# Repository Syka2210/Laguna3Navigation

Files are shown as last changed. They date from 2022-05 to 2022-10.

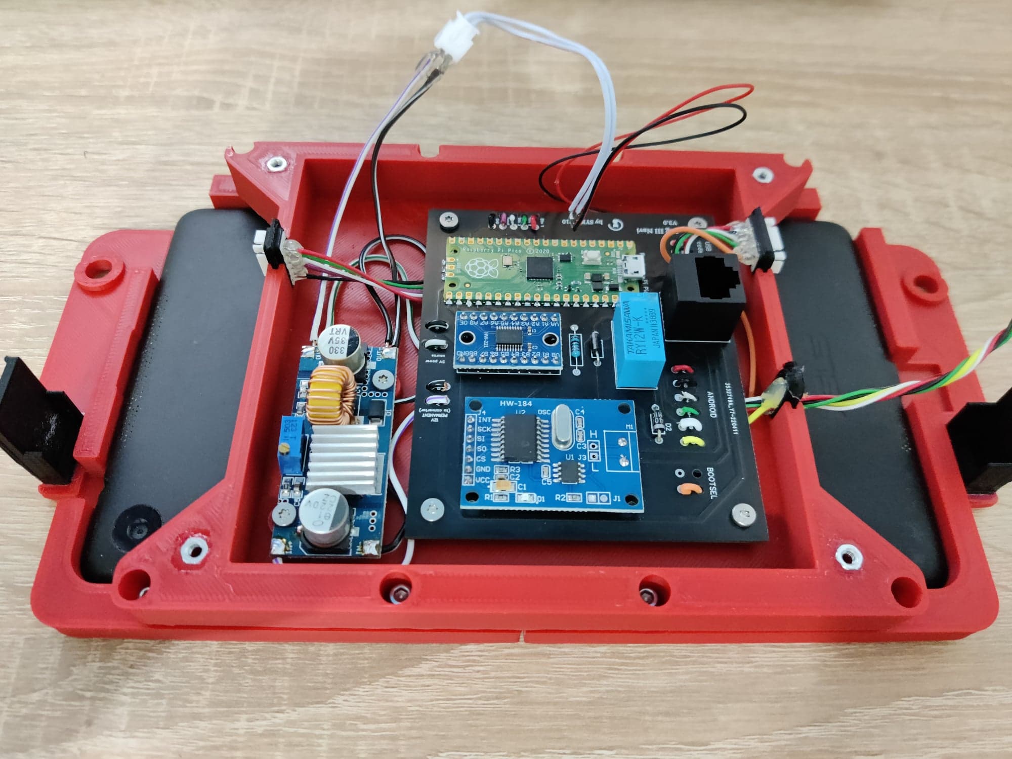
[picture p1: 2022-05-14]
Datasheets/Images/Git_image_1.jpg

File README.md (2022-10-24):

# Laguna3Navigation
   A custom navigation module for Renault Laguna III, replacing the OE screen with an Android device that comunicates with the multimedia CAN BUS network. 
Back view             |  Front view
:-------------------------:|:-------------------------:
 |  

   This project started as an alternative to the limited navigation unit that the Laguna III is equipped with (those until the R-link variant). The only difference from the aftermarket versions is the use of the OE radio. I've decided to keep the radio unit and find a way to display the info received from it to the Android device implemented, along with other useful info such as: weather info, ETA to the destination.
Also, the use of the Android navigation (Google Maps, Waze), and other apps (Spotify, YouTube, etc) was one of the main reasons for the implementation of this new multimedia interface.

   This new unit was planned as a plug in module. So no cutting of car wiring, screen fixture plastics or other trims of the car, only adding a few additional wires for a microphone and permanent power supply. 
Beeing a plug in module, the steering wheel satellite commands and the console joystick were mandatory. The satellite commands comunicate only with the radio, so that was no issue. On the other hand, the joystick for the navigation module was linked to that through CAN BUS, and that allowed me to remap the controls to my needs easily. More on that later. 

   For the android device, I had different options, with ups and downs:
- an Android tablet (Nexus 7). I have choosed that mainly for the fact that there is a kernel that allows the tablet to run in a deep sleep mode with very low curent consumption, and open in 2 seconds (no boot, since there is no complete shut down). I haven't found other tablets that have this kind of kernel, so this model was the only option. The cons - the tablet is old, runs slow, overheats quickly, hard to come by. 
- a Raspberry pi running LineageOS. This came with a few disadvantages. Big booting time, need to aquire additional modules (GPS, display, Bluetooth in some cases), high cost. On the other hand, it is more accessible (well not lately, the reason being the shortage of semiconductors), easier to work with, easier to upgrade with newer pi models, GPIO pins. 

   I've decided to use the nexus 7, at least for the first project. 

   After that being settled, the next issue at hand was acquiring the message packages sent from the radio to the navigation module ( well a part of it which is the display, so will refer to it on the rest of the presentation as the "display"). This multimedia unit uses a bitrate of 500 kbps, so accessing it was the easy part. "Decoding" all the frames received... now that was a little tricky. With the help of other who have tried something similar, but opposed to what I was trying to accomplish, I have managed to identify the following:
- each unit sends a message to announce that it is present and ready to work to the other units that may need the data from it. At the same time, this initial unit is expecting another messages from the other units to check for acknowledgement. Like pinging a server... Sort of. 
- the text messages with the icons and alignment are send using the ISO-TO (ISO 15765-2) standard. After each frame, the display sends acknowledgement frames to the radio, so I had to address that issue, or the radio would stop sending the next frames.

For reading the CAN Buss network, I started from an Arduino Uno with a MCP2515 module, and worked my way up to a Raspberry Pi Pico (due to the higher capabilities of processing data, higher Ram and flash memory, castellated holes for slim mounting, and let's be onest, for the slick look of it). 
This data needed to be sent to the Android device, and processed to show an elegant interface, similar to the original one, in order to navigate through the menu easily. That meant an app was required. So with the help of Google (literally), I've developed an app that receives the data from the Pico through the wired serial connection, and display our messages and icons same as the OE display. The app can be found here https://github.com/Syka2210/Laguna3HUD
OE display menu             |  New module display menu
:-------------------------:|:-------------------------:
 | 

This app also creates a log file with all the data received for debugging purposes. It can be enabled or disabled, depending on how the unit is performing.

The message sent to the android device from Pico consist of a string with identifiers at the beginning and at the end, and with a separator for spliting the string easily. The Pico .ino file have a detailed info for explaining how each of the function works.
Message identifier  |  Data to be displayed |  end of message identifier
:-------------------------:|:-------------------------:|:-----------------:
view_43 | FM : 3 (highlighted box) : 92.90 : 100.00 : 120.20 : KISS FM : PRO FM : DIGI FM : 1 : 2 : 3 | end_string

For the development of this project, the following sources were used:
- reverse engineering the Renault multimedia unit: https://hackaday.io/project/27439-smart-car-radio/log/67874-reverse-engineering-the-renault-update-list-display-part-1
- Android library for comunicating with Arduino through USB: https://github.com/OmarAflak/Arduino-Library
- Removing the battery from Nexus and powering it from external soucrces for eliminating the risc of battery swelling during heat summer days and risking a fire hazard: https://www.reddit.com/r/timurskernel/comments/3lui2n/video_how_to_remove_n7_battery_and_wire_direct_to/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
- Timur's kernel for deep sleep mode: https://www.reddit.com/r/timurskernel/comments/51lhgf/v40_for_android_601/   https://github.com/mehrvarz/msm-marshmallow-tm-usbhost-charge

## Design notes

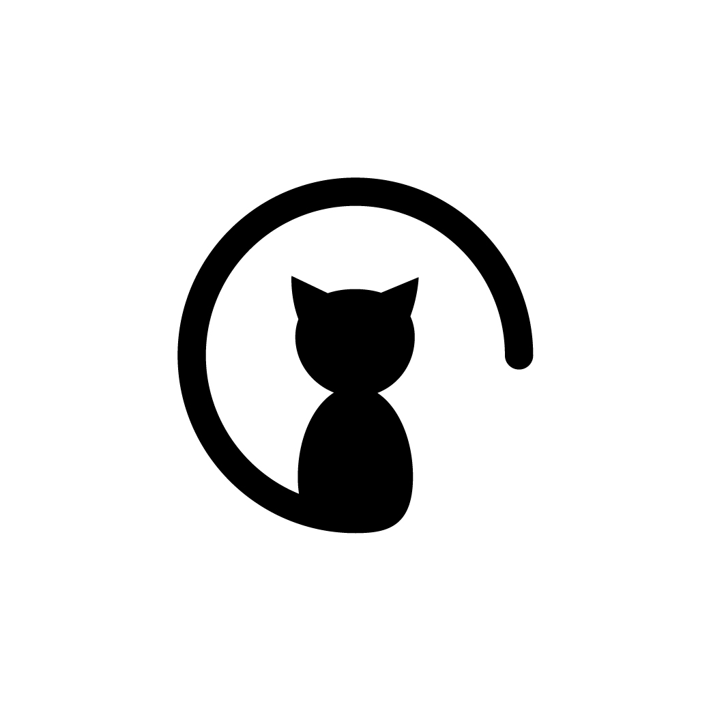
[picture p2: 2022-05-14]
PCB/Cat (29)/Cat-29.jpg

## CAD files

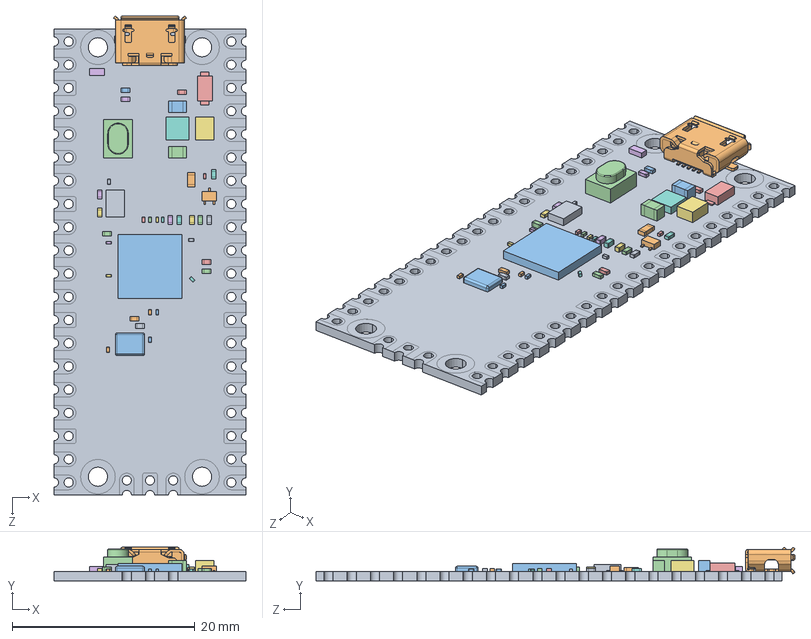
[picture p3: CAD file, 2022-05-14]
3D parts/Parts/Raspberry Pi Pico-R3.SLDASM
21.0 x 3.69 x 52.4 mm
PCB, Raspberry Pi Pico-R3.STEP
MicroUSB Port, Raspberry Pi Pico-R3.STEP
RP2040 Microcontroller, Raspberry Pi Pico-R3.STEP
SW1, Tact Switch, Raspberry Pi Pico-R3.STEP
D1, Diode, Schottky, Raspberry Pi Pico-R3.STEP
D2, QSME-C194, LED, Raspberry Pi Pico-R3.STEP
L1, Inductor, Raspberry Pi Pico-R3.STEP
U2, RT6150B-33GQW, Buck Boost Converter, Raspberry Pi Pico-R3.STEP
U3, W25Q16JVUXIQ, Serial NOR Flash 16 Mbit, Raspberry Pi Pico-R3.STEP
Q1, MOSFET, DMG1012T, Raspberry Pi Pico-R3.STEP
X1, X12M000000S096, 12 Mhz Crystal Resonator, Raspberry Pi Pico-R3.STEP
SMD Resistor, Configurable, Raspberry Pi Pico-R3_R1.STEP
SMD Resistor, Configurable, Raspberry Pi Pico-R3_R2.STEP
SMD Resistor, Configurable, Raspberry Pi Pico-R3_R3.STEP
SMD Resistor, Configurable, Raspberry Pi Pico-R3_R4.STEP
SMD Resistor, Configurable, Raspberry Pi Pico-R3_R5.STEP
SMD Resistor, Configurable, Raspberry Pi Pico-R3_R6.STEP
SMD Resistor, Configurable, Raspberry Pi Pico-R3_R7.STEP
SMD Resistor, Configurable, Raspberry Pi Pico-R3_R8.STEP
SMD Resistor, Configurable, Raspberry Pi Pico-R3_R9.STEP
SMD Resistor, Configurable, Raspberry Pi Pico-R3_R10.STEP
SMD Resistor, Configurable, Raspberry Pi Pico-R3_R11.STEP
SMD Resistor, Configurable, Raspberry Pi Pico-R3_R12.STEP
SMD Resistor, Configurable, Raspberry Pi Pico-R3_R13.STEP
SMD Resistor, Configurable, Raspberry Pi Pico-R3_R14.STEP
SMD Resistor, Configurable, Raspberry Pi Pico-R3_R15.STEP
SMD Capacitor, Configurable, Raspberry Pi Pico-R3_C1.STEP
SMD Capacitor, Configurable, Raspberry Pi Pico-R3_C2.STEP
SMD Capacitor, Configurable, Raspberry Pi Pico-R3_C3.STEP
SMD Capacitor, Configurable, Raspberry Pi Pico-R3_C4.STEP
SMD Capacitor, Configurable, Raspberry Pi Pico-R3_C5.STEP
SMD Capacitor, Configurable, Raspberry Pi Pico-R3_C6.STEP
SMD Capacitor, Configurable, Raspberry Pi Pico-R3_C7.STEP
SMD Capacitor, Configurable, Raspberry Pi Pico-R3_C8.STEP
SMD Capacitor, Configurable, Raspberry Pi Pico-R3_C9.STEP
SMD Capacitor, Configurable, Raspberry Pi Pico-R3_C10.STEP
SMD Capacitor, Configurable, Raspberry Pi Pico-R3_C11.STEP
SMD Capacitor, Configurable, Raspberry Pi Pico-R3_C12.STEP
SMD Capacitor, Configurable, Raspberry Pi Pico-R3_C13.STEP
SMD Capacitor, Configurable, Raspberry Pi Pico-R3_C14.STEP
SMD Capacitor, Configurable, Raspberry Pi Pico-R3_C15.STEP
SMD Capacitor, Configurable, Raspberry Pi Pico-R3_C16.STEP
SMD Capacitor, Configurable, Raspberry Pi Pico-R3_C17.STEP
SMD Capacitor, Configurable, Raspberry Pi Pico-R3_C18.STEP

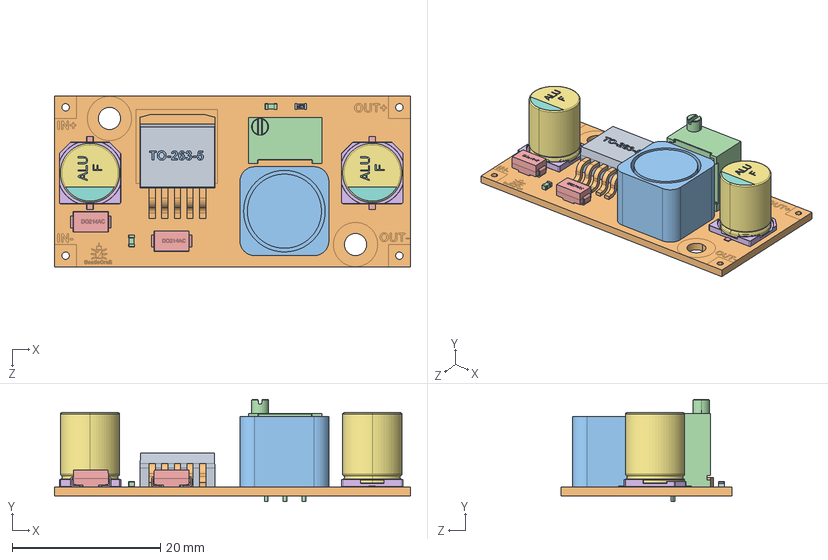
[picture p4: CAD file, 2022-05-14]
3D parts/Carcasa Navigatie V4.0/LM2596_DC-DC_CONVERTER.SLDASM
48.0 x 13.8 x 23.0 mm
User Library-DC-DC MODULE LM2596s_User Library-TO-263-5_TO-263-5_Body_1.STEP
User Library-DC-DC MODULE LM2596s_User Library-TO-263-5_TO-263-5_Leads_1.STEP
User Library-DC-DC MODULE LM2596s_User Library-TO-263-5_TO-263-5_Marking_1.STEP
User Library-DC-DC MODULE LM2596s_C0603.STEP x 2
User Library-DC-DC MODULE LM2596s_User Library-ALU-F_Pins_1.STEP x 2
User Library-DC-DC MODULE LM2596s_User Library-ALU-F_Fuss_1.STEP x 2
User Library-DC-DC MODULE LM2596s_User Library-ALU-F_K_X_F6rper_1.STEP x 2
User Library-DC-DC MODULE LM2596s_User Library-ALU-F_Beschriftung_1.STEP x 2
User Library-DC-DC MODULE LM2596s_R0603.STEP
BASE_LM2596.STEP
INDUCTOR_LM2596.STEP
POT_LM2596.STEP
DIODE_LM2596.STEP x 2

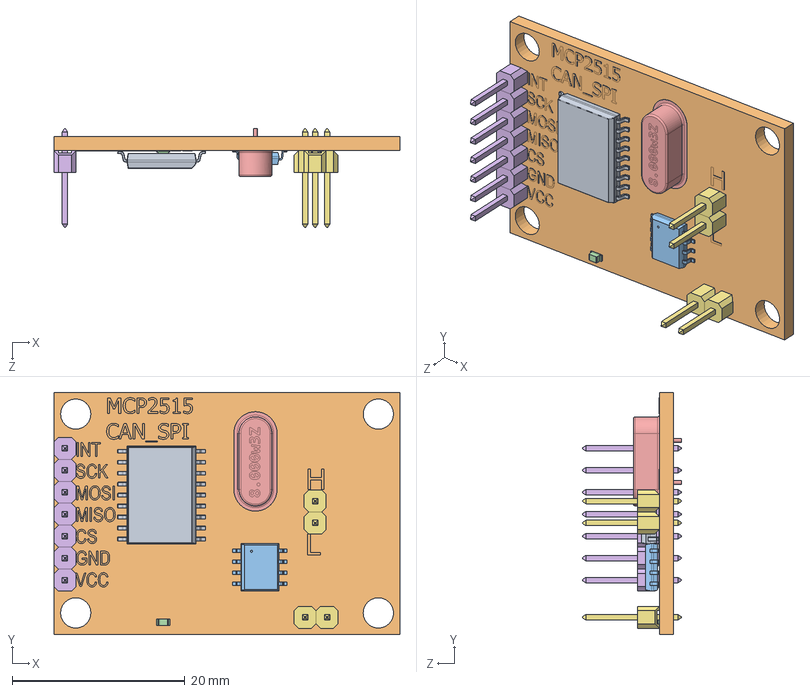
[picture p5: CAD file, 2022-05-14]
3D parts/Carcasa Navigatie V4.0/MCP2515 CAN_SPI.SLDASM
40.0 x 28.0 x 11.5 mm
so_ic_wide_18pin.stp
PCB CAN SPI.stp
so_ic_8pin.stp
led_green_0603.stp
ABRACON_ABL-8.000MHZ-B2.stp
Pin Header 7 x 1 TH 2.54mm Pitch.stp
Pin Header 2 x1 TH 2.54mm Pitch.stp x 2

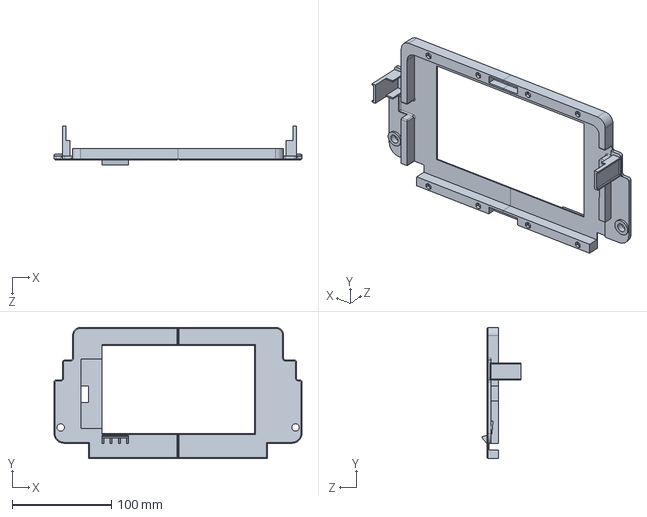
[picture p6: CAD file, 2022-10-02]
3D parts/Carcasa Navigatie V4.0/display case v4.0.SLDPRT
250.2 x 132.5 x 39.0 mm

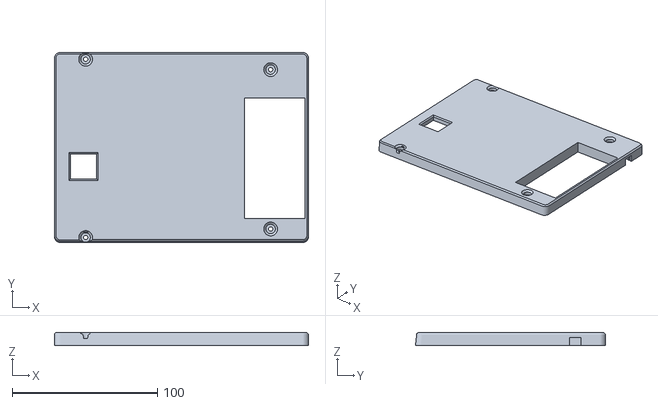
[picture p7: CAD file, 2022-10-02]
3D parts/Carcasa Navigatie V4.0/STL/PCB case - upper v4.0.STL
174.9 x 130.9 x 9.00

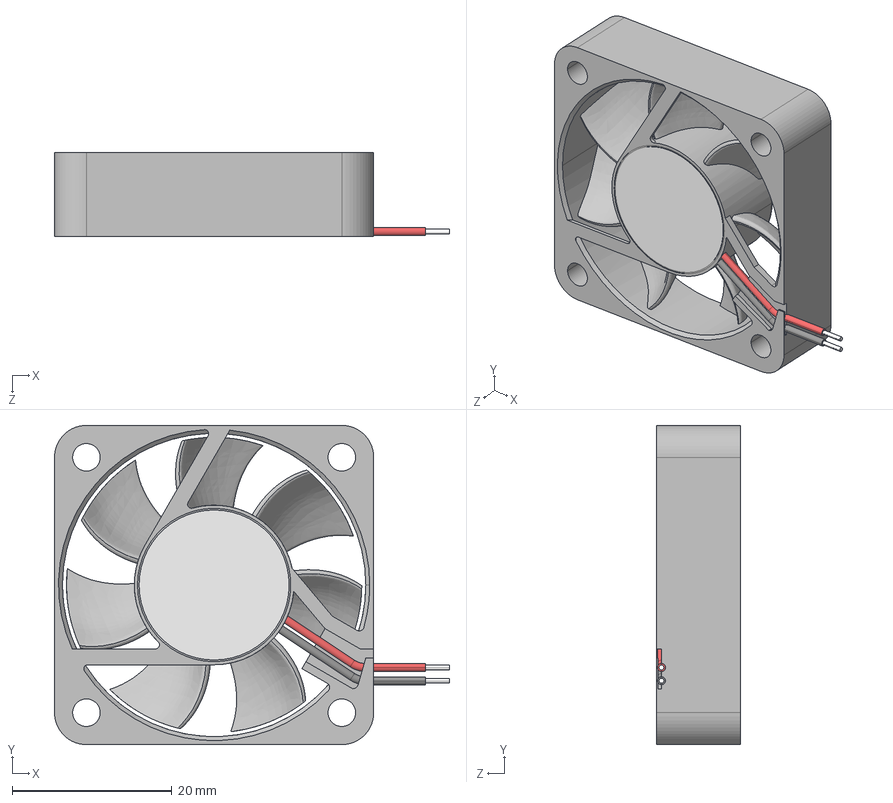
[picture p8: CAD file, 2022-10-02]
3D parts/Parts/40x40x10 DC Fan.STEP
49.5 x 40.0 x 10.5 mm

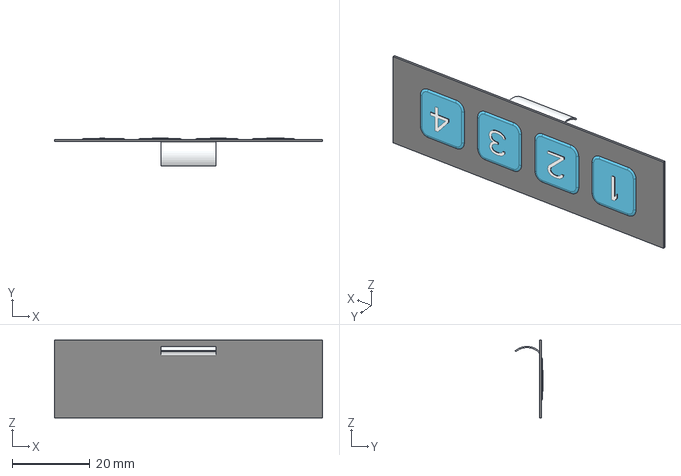
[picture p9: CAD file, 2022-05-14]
3D parts/STEP/membrane_1x4-keypad.stp
69.0 x 7.10 x 20.0 mm

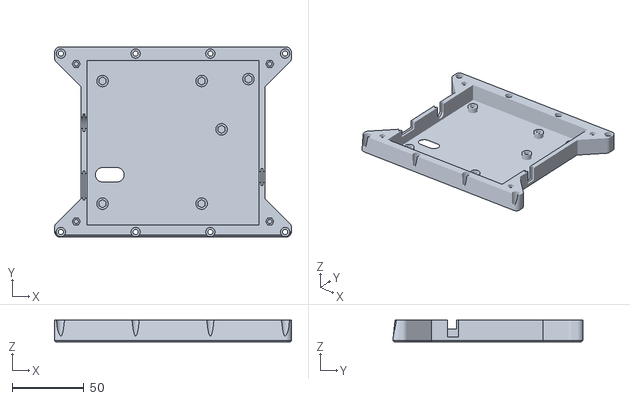
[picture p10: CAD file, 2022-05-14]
3D parts/STL files/PCB case v3.0 - lower.STL
164.9 x 132.4 x 15.0

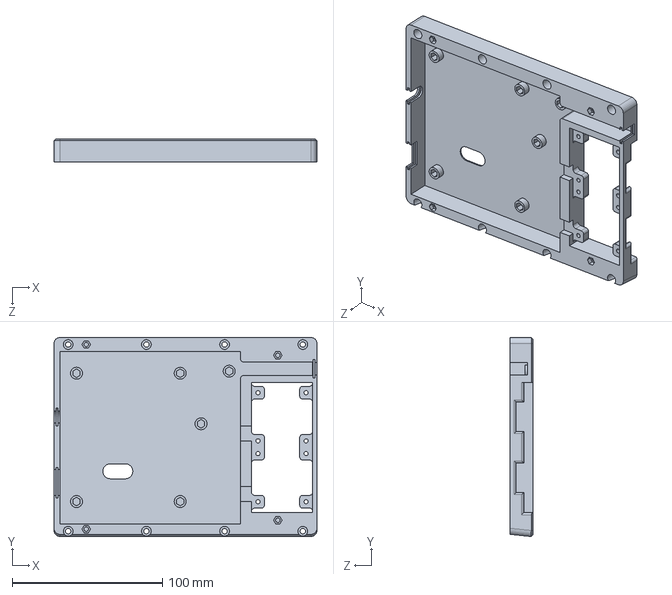
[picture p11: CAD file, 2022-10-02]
3D parts/Carcasa Navigatie V4.0/PCB case v4.0.sldprt
174.9 x 132.4 x 15.0 mm

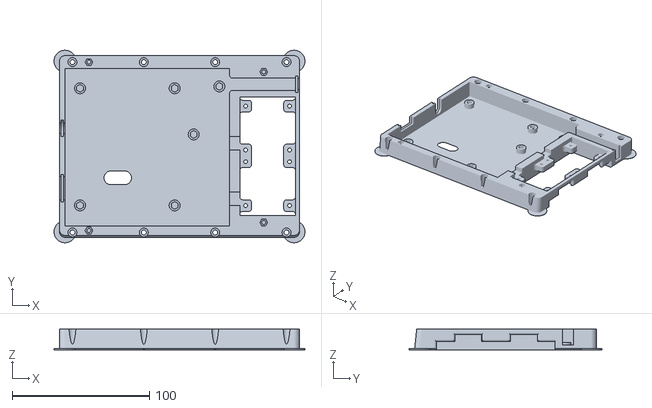
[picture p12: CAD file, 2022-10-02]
3D parts/Carcasa Navigatie V4.0/STL/PCB case - lower v4.0.STL
182.9 x 140.4 x 15.0

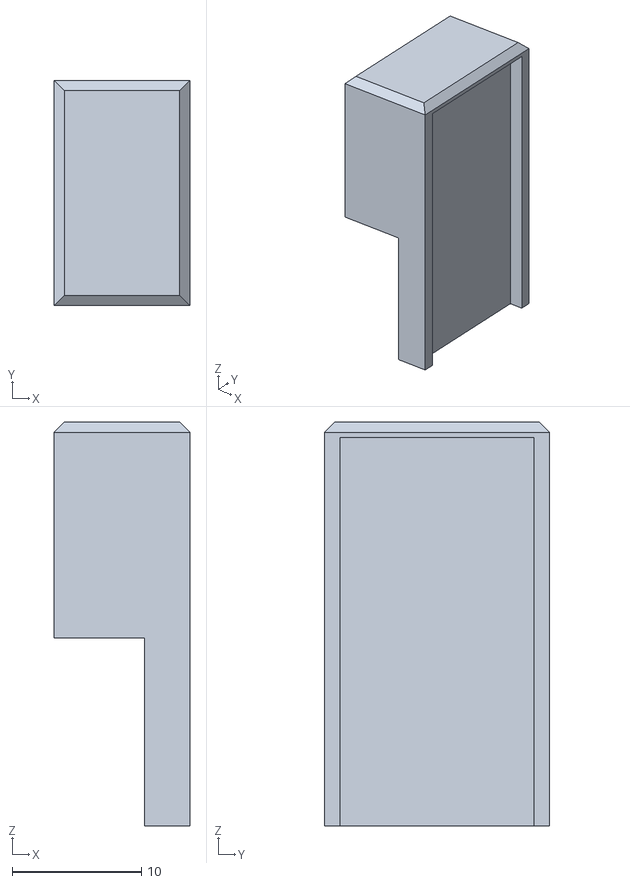
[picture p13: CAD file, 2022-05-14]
3D parts/STL files/Right clips v3.STL
10.5 x 17.4 x 31.2

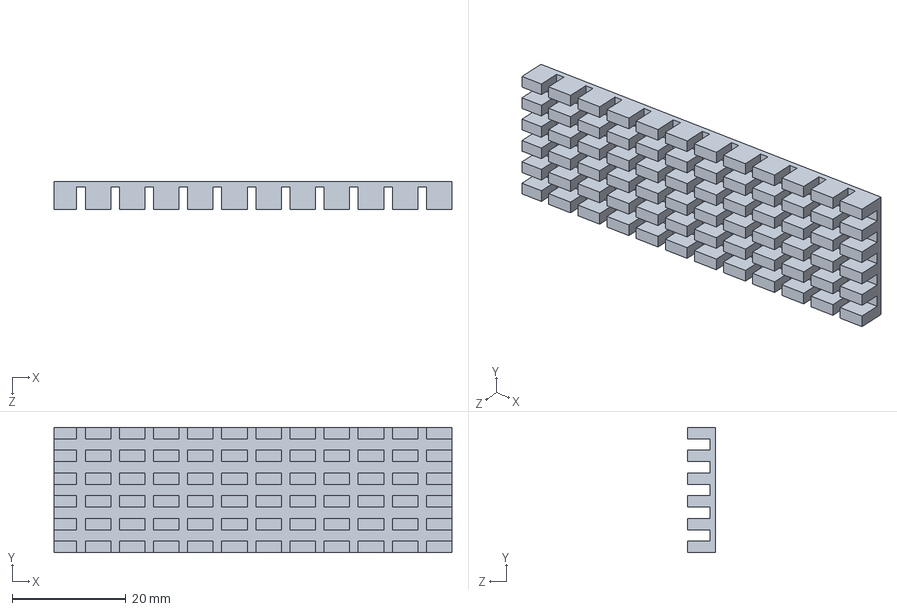
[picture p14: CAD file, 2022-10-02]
3D parts/Carcasa Navigatie V4.0/Radiator CPU.SLDPRT
70.0 x 22.0 x 5.00 mm

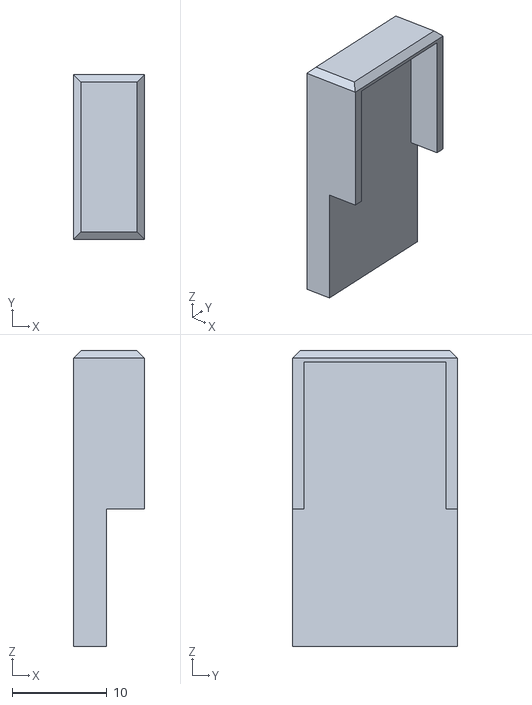
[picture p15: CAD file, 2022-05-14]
3D parts/STL files/Left clips v3.STL
7.50 x 17.4 x 31.2

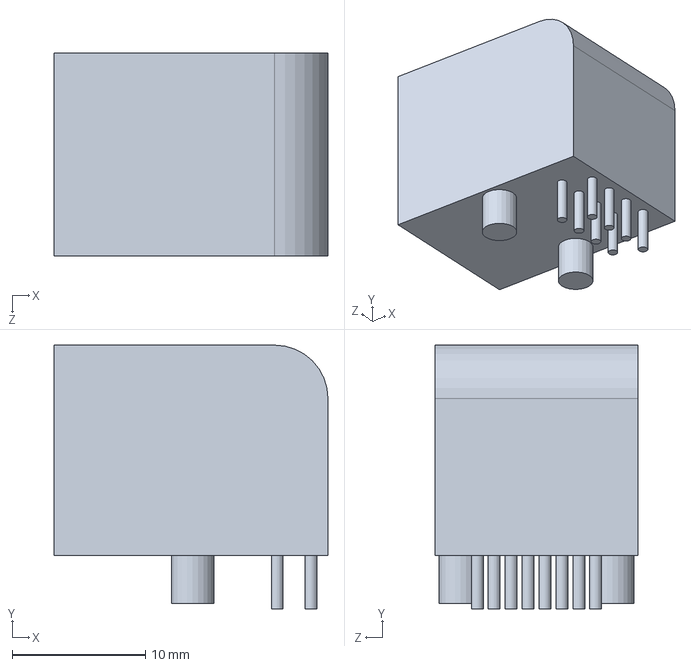
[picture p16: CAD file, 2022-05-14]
3D parts/Parts/rj45 90degree.SLDPRT
20.6 x 19.8 x 15.2 mm

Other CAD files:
3D parts/Parts/Fan_30x30x8_5V_2pin.stp
3D parts/Carcasa Navigatie V4.0/membrane_1x4-keypad.SLDPRT
3D parts/STL files/Latch V3.STL
3D parts/Parts/XH2.54 3p.SLDPRT
3D parts/Carcasa Navigatie V2.0/ACT112.SLDPRT
3D parts/Carcasa Navigatie V2.0/Display case PCB box v2.0.SLDPRT
3D parts/Carcasa Navigatie V2.0/Latch V1.2.SLDPRT
3D parts/Carcasa Navigatie V2.0/display case v1.3.SLDPRT
3D parts/Carcasa Navigatie V3.0/PCB case v3.0.sldprt
3D parts/Carcasa Navigatie V3.0/Radiator CPU.SLDPRT
3D parts/Carcasa Navigatie V3.0/display case v3.0.SLDPRT
3D parts/Carcasa Navigatie V4.0/Back_cover(display case).STL
3D parts/Carcasa Navigatie V4.0/Back_cover(display case).sldprt
3D parts/Carcasa Navigatie V4.0/Cable ring connector - 4 pins.SLDPRT
3D parts/Carcasa Navigatie V4.0/Cable ring connector.SLDPRT
3D parts/Carcasa Navigatie V4.0/Cable ring.SLDPRT
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

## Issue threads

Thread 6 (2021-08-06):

Add rigidity to the front frame clips extrusions

Syka2210, 2021-08-06:
- [x] Add rigidity to the front frame clips extrusions, by making an assembly, on wich the extrusions to be printed along the height, for improved rigidity.

- [x] Add support for the AC mask in front of the frame

Syka2210, 2022-10-02:
Solved with the new version of the frame.

Closed 2022-10-02.

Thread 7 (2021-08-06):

LOG file

Syka2210, 2021-08-06:
Implement a log file in the android device, with data (visual aided, like bolded text etc.) receiveed from the arduino and the steps that the android app makes.
**_POSSIBLE ISSUE: when exiting app, the log might not save the data_**

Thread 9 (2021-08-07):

Update the pcb with ICSP code upload, shorter connection for the arduino usb, add a 5v stab transistor for the wake up signal, remove the diode( or use a zener one), change the connector (?),

Syka2210, 2021-08-07:

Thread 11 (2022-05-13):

Tablet overheats in hot days

Syka2210, 2022-05-13:
As an alternative, consider changing the Nexus 7 with an SBC (Odroid?), but that will limit the capabilities (no Sim card no GPS)

Syka2210, 2022-10-02:
A external radiator was added with two 40mm fans to force cool the processor.

Closed 2022-10-02.

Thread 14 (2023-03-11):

Nav joy light-on

garzazum, 2023-03-11:
Incredible job! possible you have figured out CAN sequence that enables nav joy lights-on / off ?
br

Syka2210, 2023-03-11:
I haven't mapped out all the frames, only the ones that interest me. But next time I sniff the can, I will look for it.

garzazum, 2023-03-11:
Thank you for reply, I was just curious if you have it stored somewhere in past. On my own I'm limiting to China Android + radio pilot + nav joy steering on promicro. Br

Syka2210, 2023-03-11:
I haven't mapped out all the frames, only the ones that interest me. But next time I sniff the can, I will look for it.
Edit. What android device are you using?

garzazum, 2023-03-12:
Regular budget China 32/2, 7' screen fits to original 7'' navi LIII screen/frame, because of Bose and external AMP had to use 4 channel Hi to LO converter.

Syka2210, 2023-03-12:
Could you send a link of it? I'm curious what are the possibilities of it.

garzazum, 2023-03-21:
It;s something like this... https://pl.aliexpress.com/item/1005003908694349.html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

garzazum, 2023-03-21:
Also found adapter allowing to connect wire tape from radio front panel so without cutting will grab also signals from front radio panel. https://pl.aliexpress.com/item/1005004411693590.html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

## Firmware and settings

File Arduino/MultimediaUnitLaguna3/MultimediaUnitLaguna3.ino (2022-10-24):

#include <ACAN2515.h>
#include <SPI.h>
#include <Keyboard.h>

//——————————————————————————————————————————————————————————————————————————————
// The Pico has two SPI peripherals, SPI and SPI1. Either (or both) can be used.
// The are no default pin assignments to these must be set explicitly.
//——————————————————————————————————————————————————————————————————————————————
static const byte MCP2515_SCK  = 18 ; // SCK input of MCP2515
static const byte MCP2515_MOSI = 19 ; // SDI input of MCP2515
static const byte MCP2515_MISO = 16 ; // SDO output of MCP2517

static const byte MCP2515_CS  = 17 ;  // CS input of MCP2515 (adapt to your design)
static const byte MCP2515_INT = 12 ;  // INT output of MCP2515 (adapt to your design)
//——————————————————————————————————————————————————————————————————————————————
//  MCP2515 Driver object
//——————————————————————————————————————————————————————————————————————————————
ACAN2515 can (MCP2515_CS, SPI, MCP2515_INT) ;
CANMessage canMsg;
//——————————————————————————————————————————————————————————————————————————————
//  MCP2515 Quartz: adapt to your design
//——————————————————————————————————————————————————————————————————————————————
static const uint32_t QUARTZ_FREQUENCY = 8UL * 1000UL * 1000UL ; // 8 MHz
//——————————————————————————————————————————————————————————————————————————————
//  Pins for the 4x1 keypad that will be used for controlling the navigation bar of the 
//  Android device, due to the fact that it will not be accesible (frame)
//——————————————————————————————————————————————————————————————————————————————
const int backButton = 7;      // 4x1 keyboard -- button assigned for back 
const int homeButton = 8;      // 4x1 keyboard -- button assigned for home
const int appSwitchButton = 9; // 4x1 keyboard -- button assigned for app switch button
//——————————————————————————————————————————————————————————————————————————————
//  Disable or enable the log Function and the second UART data line (for debuging)
//  on pins GP0 and GP1.
//——————————————————————————————————————————————————————————————————————————————
bool logFileActive = true;
bool secondSerialActive = true;

unsigned long delayTime = 250;

unsigned char dataPackage[200];
char dataPackegePos;
int dataPackageLength;

char high_box;
String freq_box;
String last_menu;

String endString = "end_string";

String receivedMessage;
//--- Save the last main messages received in order to resend them if the app request it
String lastSource;
String lastMessage;
String lastVolume;

void sendToSerial(String viewType="zz", String frequencyType="zz", char highBox='z', String box_1x1="zz", String box_1x2="zz", String box_1x3="zz", String box_2x1="zz", String box_2x2="zz", String box_2x3="zz", String box_3x1="zz", String box_3x2="zz", String box_3x3="zz", char bass_sign='_', char bass_val='_', char treble_sign='_', char treble_val='_');

void setup() {
  //--- Start serial at highes baud rate for Android comunication
  Serial.begin(250000);
  Serial1.begin(250000);
  //--- There are no default SPI pins so they must be explicitly assigned
  SPI.setSCK(MCP2515_SCK);
  SPI.setTX(MCP2515_MOSI);
  SPI.setRX(MCP2515_MISO);
  SPI.setCS(MCP2515_CS);
  //--- Begin SPI
  SPI.begin () ;  
  //--- Configure ACAN2515
  Serial.println ("Configure ACAN2515") ;
  Serial1.println ("Configure ACAN2515") ;
  ACAN2515Settings settings (QUARTZ_FREQUENCY, 500UL * 1000UL) ; // CAN bit rate 500 kb/s - autovehicle frequency
  settings.mReceiveBufferSize = 100; // Buffer size set to 100 from 32
  settings.mRequestedMode = ACAN2515Settings::NormalMode ; // Select normal mode
  const uint16_t errorCode = can.begin (settings, [] { can.isr () ; }) ;
  //--- Turn the board LED on to check for functionality
  pinMode(LED_BUILTIN, OUTPUT);
  digitalWrite(LED_BUILTIN, HIGH);

  pinMode(backButton, INPUT_PULLUP);
  pinMode(homeButton, INPUT_PULLUP);
  pinMode(appSwitchButton, INPUT_PULLUP);
}

void logFunction(){
  //if (canMsg.id == 289){
      Serial.print("LOG-FILE:FRAME ID=");
      //Serial1.print("LOG-FILE:FRAME ID="); 
      Serial.print(canMsg.id);
      //Serial1.print(canMsg.id);
      for (int i=0; i<=7; i++){
        Serial.print(":");
        //Serial1.print(":");
        if (canMsg.data[i] < 16){
          Serial.print('0');
          //Serial1.print('0');
        } 
        Serial.print(canMsg.data[i], HEX);
        //Serial1.print(canMsg.data[i], HEX);
      }
      Serial.print(":");
      //Serial1.print(":);
      Serial.println(endString);
      //Serial1.println(endString);
  //}
}

void sendToSerial(String viewType, String frequencyType, char highBox, String box_1x1, String box_1x2, String box_1x3, String box_2x1, String box_2x2, String box_2x3, String box_3x1, String box_3x2, String box_3x3, char bass_sign, char bass_val, char treble_sign, char treble_val){
  String messagePack = "";
  if (viewType == "Error"){
    messagePack = viewType + ":" + frequencyType + ":" + endString;
    Serial.println(messagePack);
    //Serial1.println(messagePack);
  }else if (viewType == "requestMessage"){
    if (lastSource.length() > 0){
      Serial.println(lastSource);
      //Serial1.println(lastSource);
    }else{
      Serial.println("Error:last source string is empty!:end_string");
      Serial1.println("Error:last source string is empty!:end_string");
    }
    if (lastVolume.length() > 0){
      Serial.println(lastVolume);
      //Serial1.println(lastVolume);  
    }else{
      Serial.println("Error:last volume string is empty!:end_string");
      //Serial.println("Error:last volume string is empty!:end_string");
    }
    if (lastMessage.length() > 0){
      Serial.println(lastMessage);
      //Serial1.println(lastMessage);
    }else{
      Serial.println("Error:last message string is empty!:end_string");
      //Serial.println("Error:last message string is empty!:end_string");
    }
  }else if (viewType == "HighlightedBox"){
    messagePack = viewType + ":" + String(highBox) + ":" + endString;
    Serial.println(messagePack);
    //Serial1.println(messagePack);
  }else if (viewType == "view_c1"){
    messagePack = viewType + ":" + box_1x1 + ":" + box_1x2 + ":" + endString;
    lastMessage = messagePack;
    Serial.println(messagePack);
    //Serial1.println(messagePack);
  }else if (viewType == "freq_type"){
    messagePack = viewType + ":" + frequencyType + ":" + endString;
    Serial.println(messagePack);
    //Serial1.println(messagePack);
  }else if (viewType == "view_c3"){
    messagePack = viewType + ":" + box_1x1 + ":" + box_1x2 + ":" + box_1x3 + ":" + box_2x1 + ":" + box_2x2 + ":" + box_2x3 + ":" + endString;
    lastMessage = messagePack;
    Serial.println(messagePack);
    //Serial1.println(messagePack);
  }else if (viewType == "source"){
    messagePack = viewType + ":" + frequencyType + ":" + endString;
    Serial.println(messagePack);
    //Serial1.println(messagePack);
  }else if (viewType == "view_41"){
    messagePack = viewType + ":" + frequencyType + ":" + String(highBox) + ":" + box_1x1 + ":" + box_1x2 + ":" + box_1x3 + ":" + endString;
    lastMessage = messagePack;
    Serial.println(messagePack);
    //Serial1.println(messagePack);
  }else if (viewType == "device_volume"){
    messagePack = viewType + ":" + box_1x1 + ":" + endString;
    Serial.println(messagePack);
    //Serial1.println(messagePack);
  }else if (viewType == "view_43"){
    messagePack = viewType + ":" + frequencyType + ":" + String(highBox) + ":" + box_1x1 + ":" + box_1x2 + ":" + box_1x3 + ":" + box_2x1 + ":" + box_2x2 + ":" + box_2x3 + ":" + box_3x1 + ":" + box_3x2 + ":" + box_3x3 + ":" + endString;
    lastMessage = messagePack;
    Serial.println(messagePack);
    //Serial1.println(messagePack);
  }else if (viewType == "view_52"){
    messagePack = viewType + ":" + frequencyType + ":" + endString;
    lastMessage = messagePack;
    Serial.println(messagePack);
    //Serial1.println(messagePack);
  }else if (viewType == "view_63"){
    messagePack = viewType + ":" + box_1x1 + ":" + box_1x2 + ":" + box_1x3 + ":" + box_2x1 + ":" + box_2x2 + ":" + box_2x3 + ":" + endString;
    lastMessage = messagePack;
    Serial.println(messagePack);
    //Serial1.println(messagePack);
  }else if (viewType == "view_70"){
    messagePack = viewType + ":" + frequencyType + ":" + String(highBox) + ":" + endString;
    Serial.println(messagePack);
    //Serial1.println(messagePack);
  }else if (viewType == "view_73"){
    messagePack = viewType + ":" + String(highBox) + ":" + box_1x1 + ":" + box_1x2 + ":" + box_1x3 + ":" + box_2x1 + ":" + box_2x2 + ":" + box_2x3 + ":" + bass_sign + ":" + bass_val + ":" + treble_sign + ":" + treble_val + ":" + ":" + endString;
    lastMessage = messagePack;
    Serial.println(messagePack);
    //Serial1.println(messagePack);
  }
  else{
    Serial.print("viewType ");
    //Serial1.print("viewType ");
    Serial.print(viewType);
    //Serial1.print(viewType);
    Serial.println(" not found in sendToSerial method");
    //Serial1.println(" not found in sendToSerial method");
  }
}

bool bytesToArray(int arrayLength){
  int arrayPos = 0;
  bool loop = true;
  logFunction();
  for (int i = 2; i <= 7; i++){
    dataPackage[arrayPos] = canMsg.data[i];
    arrayPos++;
  }
  while (loop == true){
    if (can.receive (canMsg)){
      if (canMsg.id == 289){
        if (canMsg.data[0] == 0x10){
          Serial.println("Info:FAILED:Received new data package before ariving to the end of the previous one");
          break;
        }
        logFunction();
        for (int i = 1; i <= 7; i++){    
          dataPackage[arrayPos] = canMsg.data[i];
          if (arrayPos == arrayLength){
            loop = false;
            break;
          }else{
            arrayPos++;        
          }
        }
      }
    }
  }
  
  for (int i = 0; i <= arrayPos; i++){
    Serial.print(dataPackage[i], HEX);
    Serial.print(":");
  }
  Serial.println();

  if (arrayPos != arrayLength){
    Serial.print("Info:Error: data package length not identical to array => ");
    Serial.print(arrayPos);
    Serial.println(endString);
  }else{
    Serial.println("Info:Package length correct!!!");
  }

  Serial.println("------------------------------------------------------------");

  if (dataPackage[1] == 0x00 && dataPackage[0] == 0x20){
    highlighted_box(dataPackage[11]);
    return true;
  }
    
  if (dataPackage[1] == 0xC1 && dataPackage[5] != 0x00){
    Serial.println("entering view_C1");
    view_C1(arrayLength);
    return true;
  }
  if (dataPackage[1] == 0xC1 && dataPackage[5] == 0x00){
    freq_type(arrayLength);
    return true;
  }
  if (dataPackage[1] == 0xC3){
    Serial.println("entering view_C3");
    view_C3(arrayLength);
    return true;
  }
  
  if (dataPackage[1] == 0x41 && dataPackage[0] == 0x25){
    view_41(arrayLength);
    return true;
  }
  if (dataPackage[1] == 0x41 && dataPackage[0] == 0x35){
    view_41_main_volume(arrayLength, false);
    return true;
  }
  if (dataPackage[1] == 0x00 && dataPackage[0] == 0x08){
    view_41_main_volume(arrayLength, true);
    return true;
  }
  if (dataPackage[1] == 0x43){
    // --- Check to see if the data package is the Memory menu, or the normal radio display
    // and send the second parameter true for memory or false.
    if (dataPackage[2 == 0x7A]){
      view_43(arrayLength, true);      
    }else view_43(arrayLength, false);
    return true;
  }
  if (dataPackage[1] == 0x52){
    view_52(arrayLength);
    return true;
  }
  if (dataPackage[1] == 0x63){
    view_63(arrayLength);
    return true;
  }
  if (dataPackage[1] == 0x73){
    view_73(arrayLength);
    return true;
  }

  return false;
}

//——————————————————————————————————————————————————————————————————————————————
//  Get the array position for the text matrix (3x3)
//——————————————————————————————————————————————————————————————————————————————
int get_array_position(int columnNr, int rowNr) {
  int arrayPos = 0;
  if (columnNr == 1)
  {
    if (rowNr == 1) arrayPos = 1;
    else if (rowNr == 2) arrayPos = 2;
    else if (rowNr == 3) arrayPos = 3;
  }
  else if (columnNr == 2)
  {
    if (rowNr == 1) arrayPos = 4;
    else if (rowNr == 2) arrayPos = 5;
    else if (rowNr == 3) arrayPos = 6;
  }
  else if (columnNr == 3)
  {
    if (rowNr == 1) arrayPos = 7;
    else if (rowNr == 2) arrayPos = 8;
    else if (rowNr == 3) arrayPos = 9;
  }
  return arrayPos;
}

//——————————————————————————————————————————————————————————————————————————————
//  Find and save the highlighted box
//——————————————————————————————————————————————————————————————————————————————
void highlighted_box(char value){
  if (value == 0x20){
    sendToSerial("HighlightedBox", "", '1');
    high_box = '1';
  }else if (value == 0x21){
    sendToSerial("HighlightedBox", "", '2');
    high_box = '2';
  }else if (value == 0x22){
    sendToSerial("HighlightedBox", "", '3');
    high_box = '3';    
  }else if (value == 0x23){
    sendToSerial("HighlightedBox", "", '4');
    high_box = '4';
  }else sendToSerial("Error", "Highlighted_box function received wrong data");
}

//Channel number function -- CHECKED
String chan_number(char recv_char){
  String ch_nr;
  switch(recv_char){
    case 0x10:
      ch_nr = "1";
      break;
    case 0x11:
      ch_nr = "2";
      break;
    case 0x12:
      ch_nr = "3";
      break;
    case 0x13:
      ch_nr = "4";
      break;
    case 0x14:
      ch_nr = "5";
      break;
    case 0x15:
      ch_nr = "6";
      break;
    case 0x46:
      ch_nr = "7";
      break;
    case 0x47:
      ch_nr = "8";
      break;
    case 0x48:
      ch_nr = "9";
      break;
    case 0x49:
      ch_nr = "10";
      break;
    case 0x4A:
      ch_nr = "11";
      break;
    case 0x4B:
      ch_nr = "12";
      break;
    default:
      ch_nr = "0";
      break;
    }

  return ch_nr;
}

String icons(char input){
  String iconOutput;

  switch (input){
    case 0x01:
      iconOutput = "icon_Audio_settings";
      break;
    case 0x02:
      iconOutput = "icon_Phone_settings";
      break;
    case 0x03:
      iconOutput = "icon_System_settings";
      break;
    case 0x04:
      iconOutput = "icon_Bluetooth";
      break;
    case 0x05:
      iconOutput = "icon_Language";
      break;
    case 0x06:
      iconOutput = "icon_Sound_optimization";
      break;
    case 0x07:
      iconOutput = "icon_Musical_atmosphere";
      break;
    case 0x08:
      iconOutput = "icon_Display_CD_time";
      break;
    case 0x09:
      iconOutput = "icon_Radio_functions";
      break;
    case 0x0A:
      iconOutput = "icon_Serious_classics";
      break;
    case 0x0B:
      iconOutput = "icon_Varied_speech";
      break;
    case 0x0C:
      iconOutput = "icon_News";
      break;
    case 0x0D:
      iconOutput = "icon_Sport";
      break;
    case 0x0E:
      iconOutput = "icon_Pop_music";
      break;
    case 0x1A:
      iconOutput = "icon_Pair_phone";
      break;
    case 0x12:
      iconOutput = "icon_Music_note";
      break;
    case 0x13:
      iconOutput = "icon_Vehicle_phonebook";
      break;
    case 0x14:
      iconOutput = "icon_Vehicle_phonebook"; // Mobile_phonebook
      break;
    case 0x15:
      iconOutput = "icon_Call_history";
      break;
    case 0x16:
      iconOutput = "icon_Mailbox";
      break;
    case 0x17:
      iconOutput = "icon_Directory_management";
      break;
    case 0x18:
      iconOutput = "icon_Other_audio_settings";
      break;
    case 0x1D:
      iconOutput = "icon_Missed_calls";
      break;
    case 0x1E:
      iconOutput = "icon_Received_calls";
      break;
    case 0x1F:
      iconOutput = "icon_Dialed_numbers";
      break;
    case 0x20:
      iconOutput = "icon_Put_on_hold";
      break;
    case 0x21:
      iconOutput = "icon_USB";
      break;
    case 0x24:
      iconOutput = "icon_Volume";
      break;
    case 0x25:
      iconOutput = "icon_Ringtone";
      break;
    case 0x26:
      iconOutput = "icon_Cercle_full";
      break;
    case 0x27:
      iconOutput = "icon_Cercle_empty";
      break;
    case 0x28:
      iconOutput = "icon_Checked_box";
      break;
    case 0x29:
      iconOutput = "icon_Unchecked_box";
      break;
    case 0x2A:
      iconOutput = "icon_Folder";
      break;
    case 0x2B:
      iconOutput = "icon_Voice_prompt_volume";
      break;
    case 0x40:
      iconOutput = "icon_number_1";
      break;
    case 0x41:
      iconOutput = "icon_number_2";
      break;
    case 0x42:
      iconOutput = "icon_number_3";
      break;
    case 0x43:
      iconOutput = "icon_number_4";
      break;
    case 0x44:
      iconOutput = "icon_number_5";
      break;
    case 0x60:
      iconOutput = "icon_Adaptation_volume";
      break;
    case 0x62:
      iconOutput = "icon_Emergency";
      break;
    default:
      break;
  }
  
  return iconOutput;
}
//—————————————————————————————————————————————————————————————————————————————————————————————————————————————————
//  A one row / two columns view, usually with an icon in the first column, and text on the second
//  There may be instances where in the second column we have additional icons (mainly in the settings - bluetooth)
//  ||icon||TEXT||
//—————————————————————————————————————————————————————————————————————————————————————————————————————————————————
// ADD A TEXT CONCATENATION FOR FREQUENCY TYPE VISIBLE INSTEAD OF THE ICONS
//—————————————————————————————————————————————————————————————————————————————————————————————————————————————————
void view_C1(int arrayLength){
  String viewC1[3];
  int arrayPos = 1;
  bool start_titles = false;
  char character;
  String iconText;
  for (int i = 19; i <= arrayLength; i++){
    if (dataPackage[i] == 0xF1){
      viewC1[arrayPos] = icons(dataPackage[i+1]);
      continue;
    }
    // Check for column change
    if (dataPackage[i] == 0x00 && dataPackage[i+1] == 0x00 && i < arrayLength-3){
      arrayPos = 2;
      start_titles = true;
      // Skip the 0x00 column separator bits (2 or 3)      
      if (dataPackage[i+2] == 0x00) i = i+2;
      else i = i+1;      
      continue;
    }
    if (start_titles == true && dataPackage[i] >= 0x20 && dataPackage[i] <= 0x7E){
      character = dataPackage[i];
      viewC1[arrayPos].concat(character);
    }
  }
  sendToSerial("view_c1", "", '_', viewC1[1], viewC1[2]);
}
//—————————————————————————————————————————————————————————————————————————————————————————————————————————————————
//  A HIDDEN one row / two columns view, with text on both columns for the frequency type box on the view_41 and
//  view_43 functions. We will save the first box text in a global variable to be used in those functions.
//  || text ||TEXT||
//—————————————————————————————————————————————————————————————————————————————————————————————————————————————————
void freq_type(int arrayLength){
  String freq[3];
  int arrayPos = 1;
  bool start_titles = false;
  char character;
  String iconText;
  for (int i = 20; i <= arrayLength; i++){
    // Check for column change
    if (dataPackage[i] == 0x00 && dataPackage[i+1] == 0x00 && i < arrayLength-3){
      arrayPos = 2;
      // Skip the 0x00 column separator bits (2 or 3)      
      if (dataPackage[i+2] == 0x00) i = i+2;
      else i = i+1;      
      continue;
    }
    if (dataPackage[i] >= 0x20 && dataPackage[i] <= 0x7E){
      character = dataPackage[i];
      freq[arrayPos].concat(character);
    }
  }
  freq_box = freq[1];
  sendToSerial("freq_type", freq[1]);
}
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
void loop() {
  // --- Check for message request from Android device on app startup to send the last messages memorized
  if (Serial.available() > 0){
    while (Serial.available() > 0){
      char s = Serial.read();
      receivedMessage.concat(s);
      if (receivedMessage == "reqMsg"){
        // ---- Here we send all the last messages memorized.
        sendToSerial("requestMessage");
        receivedMessage = "";
      }
    }
    receivedMessage = "";
  }
  // --- Search for 4x1 keypad button press
  if (!digitalRead(backButton)){
        Keyboard.press(KEY_ESC);
        Serial.println("KEY_ESC");
        delay(delayTime);
        Keyboard.releaseAll();
  }
  if (!digitalRead(homeButton)){
        Keyboard.press('h');
        Serial.println("h");
        delay(delayTime);
        Keyboard.releaseAll();
  }
  if (!digitalRead(appSwitchButton)){
        Keyboard.press('s');
        Serial.println("s");
        delay(delayTime);
        Keyboard.releaseAll();
  }
  // --- Scan for ISO-TP format message package and send it to be saved in an array
  // !!! TO DO - Remove the debugging lines !!!
  if (can.receive (canMsg)){
    if (canMsg.id == 289){
      int packageLength = 0;
      Serial.println("RETURNED TO LOOP");
      if (canMsg.data[0] == 0x10){
        packageLength = canMsg.data[1];
        Serial.print("package length is: ");
        Serial.println(packageLength);
      
        if (bytesToArray(packageLength - 1) == false){
          Serial.print("Info:Error: data package not recognized:");
          Serial.println(endString);
        }else {
          Serial.print("Info:Succes: data package recognized:");
          Serial.println(endString);
          Serial.println("######################################################");
          Serial.println();
          Serial.println();
          Serial.println();
        }
      }
    }else if (canMsg.id == 1597){
      keyboardButtons(canMsg.data[0]);
    }else if (canMsg.id == 1598){
      keyboardJoystick(canMsg.data[0], canMsg.data[1]);      
    }
  }
}

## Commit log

2021-05-10 First upload
    Uploaded all the current files.
2021-05-10 3D parts
    Added the 3D parts and the STL files.
    [Ansamblu_Carcasa_Nexus7 V1.3.SLDASM, Display case PCB box v1.3.SLDPRT, Display case PCB box_lower.SLDPRT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]
2021-05-14 Updated Layouts, Changed Arduino Functions
    Modified Arduino functions to be more compact.
    Added icons.
    Changed Android Input. Eliminated unnecessary Functions
2021-05-19 Function + App Update
    Arduino:
    -added the Keyboard functions for ProMicro board
    -added infoBox function
    -fixed some bugs
    Android APP:
    -implemented screen always ON
    -fixed musicalAtmosphere display
    3D parts:
    -added connector 3D part
    [Display connector.SLDPRT]
2021-05-30 Arduino Code changes
    Added some files to .gitignore that were automagically updated by Android Studio.
    Changed two if chains to switch cases. Added a get_array_position function to be used later and tidied up the code that will eventually be replaced by it.
2021-06-01 Update + bug fix
    Implemented xhdpi and xxhdpi display size layout.
    Started a log file for debugging on android app.
    Added a "memory request" when the app restarts, so it will show the last message the arduino.
    Fixed some bugs.
    Added the PCB layout.
    Had fun.
2021-06-03 Functionality update
    PopUp menu for the navigation and spotify .
    Implemented the controls on the popUp menu from the joystick.
    Added satellite commands.
    [app_selection_menu.xml]
2021-06-06 Functions update
    Changed the volume function (added the pause, return from pause).
    Trimmed the Serial.print mess.
2021-06-12 Update
    Fixed reqMsg function
    Added the display sync function (UpdateListDisplay) in the Arduino folder.
2021-06-12 Updated the PCB
    Finalized the PCB
    [Gerber_BoardOutline.GKO, Gerber_BottomLayer.GBL, Gerber_BottomSilkLayer.GBO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]
2021-07-28 Started implementing weather method
    [ACT112.SLDPRT, Display case PCB box v1.3 - lower.STL, Display case PCB box v1.3 - upper.STL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]
2021-08-11 Updated the 3D parts
    Added a larger chamfer for the holes, separated the front frame in multiple parts for rigidity and easy print, added a big chamfer for AC channel.
    [Body10.sldprt, Body3.sldprt, Body4.sldprt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]
2021-12-03 PCB update
    PCB V2.0 + case modifications.
    [ACT112.SLDPRT, Body10.sldprt, Body3.sldprt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]
2022-05-14 Major Updates
    Changed the Arduino to a Raspberry Pi Pico for faster processing.
    Changed the PCB layout, changed the relay, got rid of connectors, added RJ45 connector for easier connection.
    Changed the case, more modular.
    Finished the weather function.
    Finished the log function.
    [ACT112.SLDPRT, Back_cover(display case).STL, Back_cover(display case).sldprt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]
2022-10-02 Another aproach
    Modified the case, changed the sketch to get the hole message package (using the ISO-15765-2 protocol)
    [40x40x10 DC Fan.SLDPRT, 40x40x10 DC Fan.STEP, Back_cover(display case).STL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]
2022-10-24 Major changes
    Updated the RP Pi source code. Removed the Android app to a separate repository.
    [app_selection_menu.xml]
